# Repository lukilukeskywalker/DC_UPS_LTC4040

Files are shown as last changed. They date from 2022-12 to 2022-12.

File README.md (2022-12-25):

# DC_UPS_LTC4040
Low power Uninterrupible Power Supply based on the LTC4040
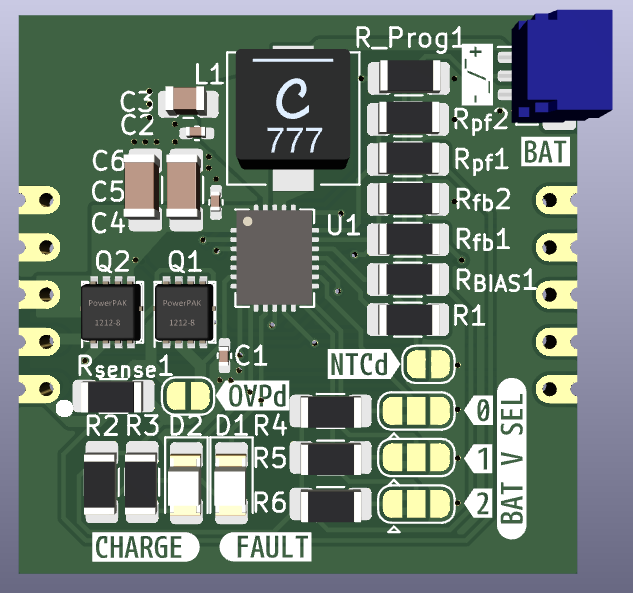
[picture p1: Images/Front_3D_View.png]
3D Board_Front


*The LTC4040 is a complete 3.5V to 5.5V supply rail battery backup system. It contains a high current step-up DC/DC regulator to back up the supply from a single-cell Li-Ion or LiFePO4 battery.*
Picked from the datasheet.

So yeah, This is supposed to be a place in module for Low Power systems that need to keep functioning when power goes off. The dimensions of the module are 30 x 30 mm, and it can be configured (as stated in the datasheet) to support different battery chemistries, and to disable or enable features like Overvoltage protection or Temperature Control of the battery

Everything is described in the schematic:
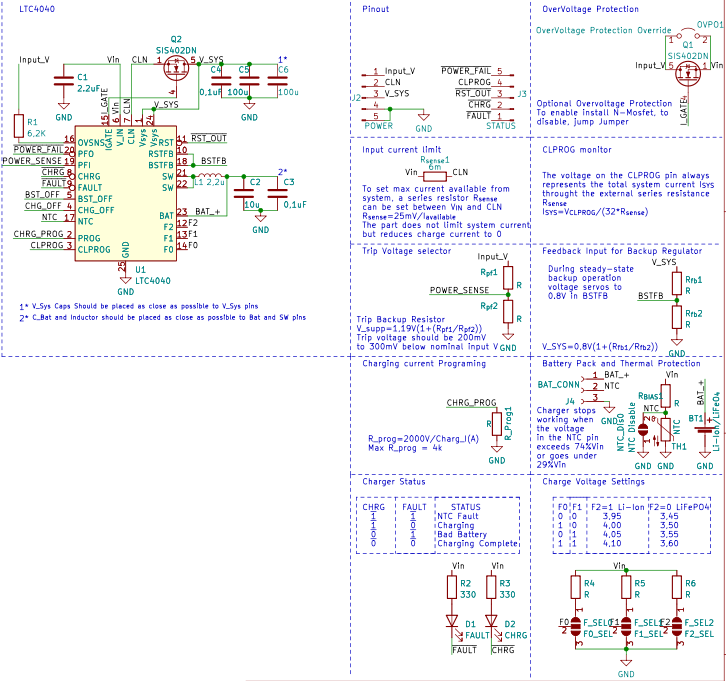
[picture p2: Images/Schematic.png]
Schematic


And the board design is Included:

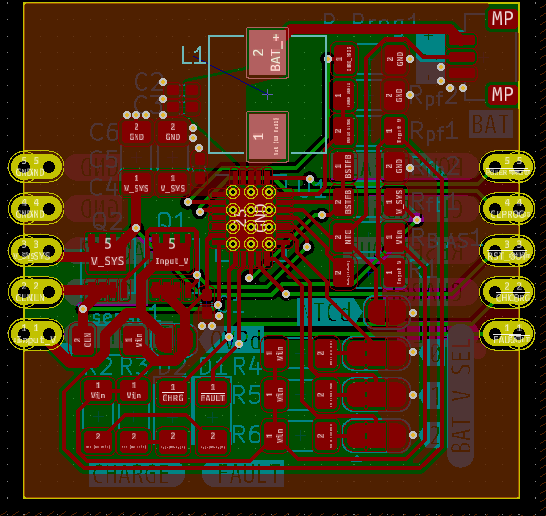
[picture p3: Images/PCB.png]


The board hasn't been tested yet, so take with care. 
Also I do not take any responsability or problems that may arrise with its use

### Proyects that may arrise Interest to the readers:
- [The Ultimate Single Cell Lithium UPS for any Raspberry Pi](https://hackaday.io/project/162653/logs?sort=oldest)
- [LTC4040 5V, 2.5A Uninterruptible Power Supply (UPS) with USB-C](https://www.beyondlogic.org/ltc4040-5v-2-5a-uninterruptible-power-supply-ups-with-usb-c/)

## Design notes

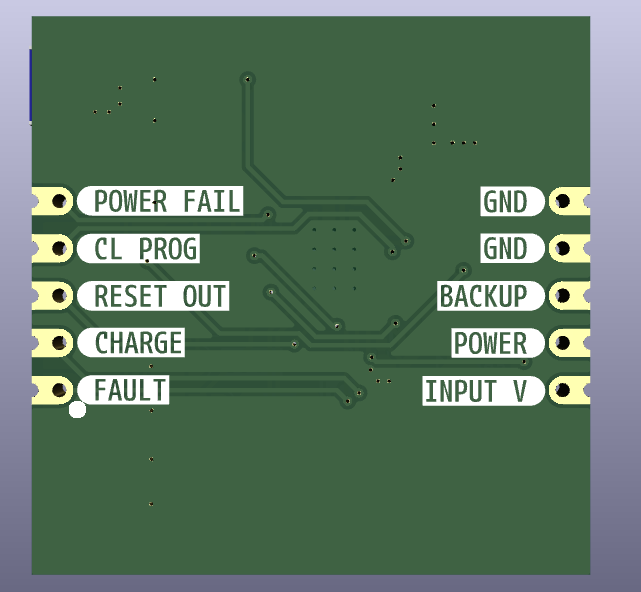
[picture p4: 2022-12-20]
Images/Back_3D_View.png

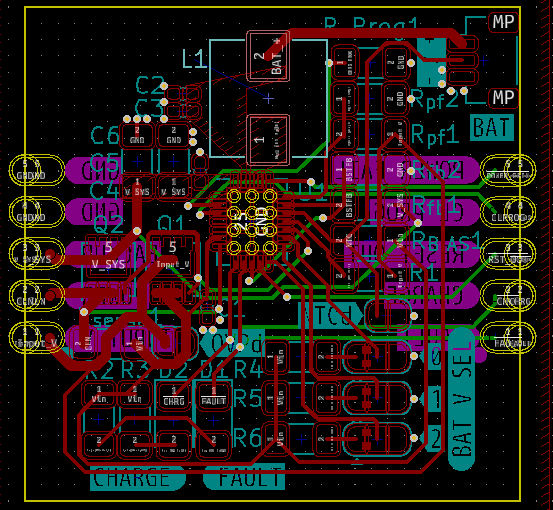
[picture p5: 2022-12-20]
Images/PCB INLINE VIEW.png

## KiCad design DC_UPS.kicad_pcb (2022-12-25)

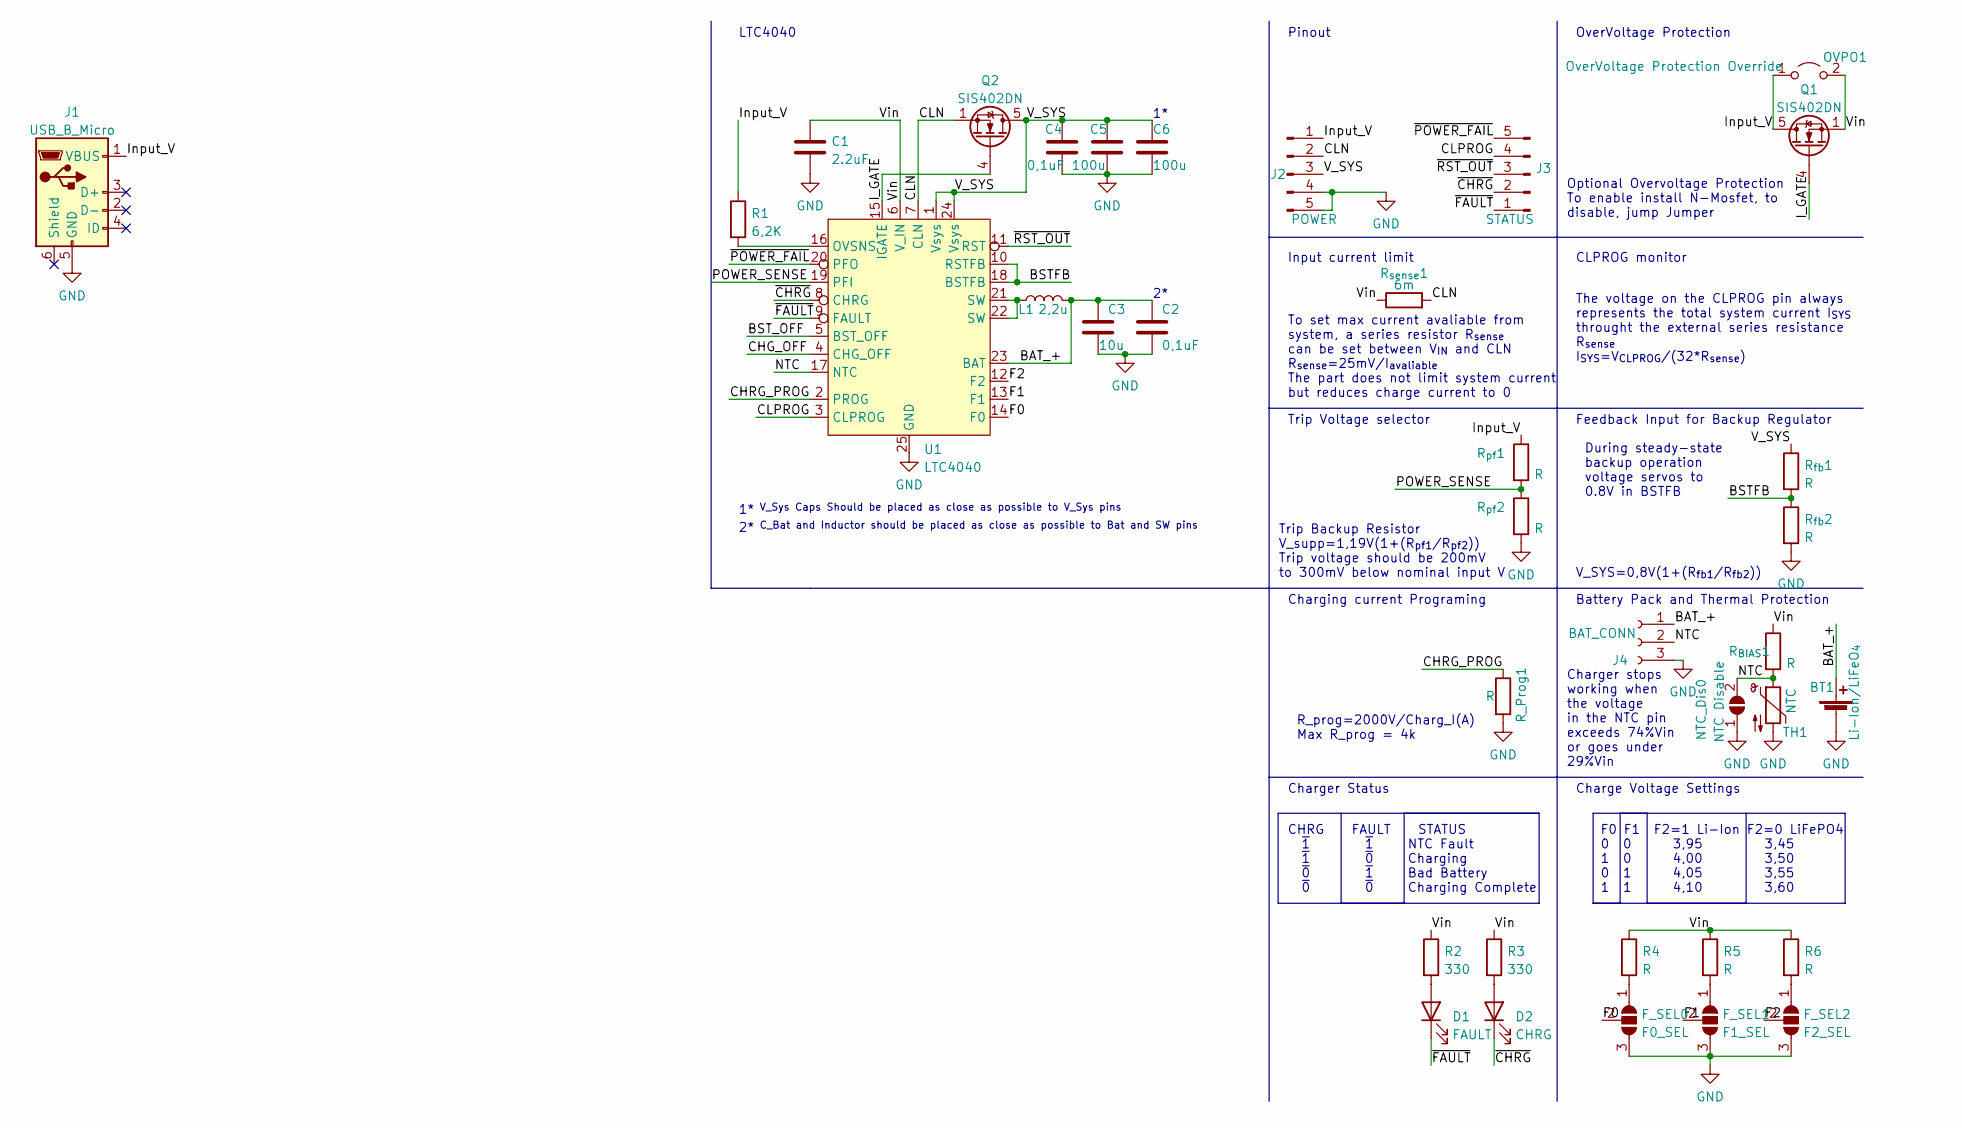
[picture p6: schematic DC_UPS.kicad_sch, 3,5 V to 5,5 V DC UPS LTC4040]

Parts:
BT1: Li-Ion/LiFeO_{4}; TE_1776119-2
C1: 2.2uF; C_0402_1005Metric_Pad0.74x0.62mm_HandSolder
C2, C4: 0,1uF; C_0402_1005Metric_Pad0.74x0.62mm_HandSolder
C3: 10u; C_0805_2012Metric_Pad1.18x1.45mm_HandSolder
C5, C6: 100u; C_1206_3216Metric_Pad1.33x1.80mm_HandSolder
D1: FAULT; LED_1206_3216Metric_Pad1.42x1.75mm_HandSolder
D2: CHRG; LED_1206_3216Metric_Pad1.42x1.75mm_HandSolder
F_SEL0: F0_SEL; SolderJumper-3_P1.3mm_Bridged2Bar12_RoundedPad1.0x1.5mm
F_SEL1: F1_SEL; SolderJumper-3_P1.3mm_Bridged2Bar12_RoundedPad1.0x1.5mm
F_SEL2: F2_SEL; SolderJumper-3_P1.3mm_Bridged2Bar12_RoundedPad1.0x1.5mm
J1: USB_B_Micro; TE_2013499-1
J2: POWER; CastellatedPinHeader_2.54mm_5
J3: STATUS; CastellatedPinHeader_2.54mm_5
J4: BAT_CONN; JST_SH_BM03B-SRSS-TB_1x03-1MP_P1.00mm_Vertical
L1: 2,2u; L_Wuerth_HCI-7030
NTC_Dis0: NTC Disable; SolderJumper-2_P1.3mm_Open_RoundedPad1.0x1.5mm
OVPO1: OverVoltage Protection Override; SolderJumper-2_P1.3mm_Open_RoundedPad1.0x1.5mm
Q1, Q2: SIS402DN; Vishay_PowerPAK_1212-8_Single
R1: 6,2K; R_1206_3216Metric_Pad1.30x1.75mm_HandSolder
R2, R3: 330; R_1206_3216Metric_Pad1.30x1.75mm_HandSolder
R4, R5, R6: R; R_1206_3216Metric_Pad1.30x1.75mm_HandSolder
R_Prog1: R; R_1206_3216Metric_Pad1.30x1.75mm_HandSolder
R_{BIAS}1: R; R_1206_3216Metric_Pad1.30x1.75mm_HandSolder
R_{fb}1, R_{fb}2: R; R_1206_3216Metric_Pad1.30x1.75mm_HandSolder
R_{pf}1, R_{pf}2: R; R_1206_3216Metric_Pad1.30x1.75mm_HandSolder
R_{sense}1: 6m; R_1206_3216Metric_Pad1.30x1.75mm_HandSolder
TH1: NTC; R_Axial_DIN0204_L3.6mm_D1.6mm_P2.54mm_Vertical
U1: LTC4040; QFN-24-1EP_4x5mm_P0.5mm_EP2.65x3.65mm_ThermalVias

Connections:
/BAT_+: BT1.1 (+), C2.1, C3.1, J4.1, L1.2, U1.23 (BAT)
/BSTFB: R_{fb}1.2, R_{fb}2.1, U1.10 (RSTFB), U1.18 (BSTFB)
/BST_OFF: U1.5 (BST_OFF)
/CHG_OFF: U1.4 (CHG_OFF)
/CHRG_PROG: R_Prog1.1, U1.2 (PROG)
/CLN: J2.2, Q2.1 (S), Q2.2 (S), Q2.3 (S), R_{sense}1.2, U1.7 (CLN)
/CLPROG: J3.4, U1.3 (CLPROG)
/F0: F_SEL0.2 (C), U1.14 (F0)
/F1: F_SEL1.2 (C), U1.13 (F1)
/F2: F_SEL2.2 (C), U1.12 (F2)
/I_GATE: Q1.4 (G), Q2.4 (G), U1.15 (IGATE)
/Input_V: J1.1 (VBUS), J2.1, OVPO1.1 (A), Q1.5 (D), R1.1, R_{pf}1.1
/NTC: J4.2, NTC_Dis0.2 (B), R_{BIAS}1.2, TH1.1, U1.17 (NTC)
/POWER_SENSE: R_{pf}1.2, R_{pf}2.1, U1.19 (PFI)
/V_SYS: C4.1, C5.1, C6.1, J2.3, Q2.5 (D), R_{fb}1.1, U1.1 (Vsys), U1.24 (Vsys)
/Vin: C1.1, OVPO1.2 (B), Q1.1 (S), Q1.2 (S), Q1.3 (S), R2.1, R3.1, R4.1, R5.1, R6.1, R_{BIAS}1.1, R_{sense}1.1, U1.6 (V_IN)
/~CHRG: D2.1 (K), J3.2, U1.8 (CHRG)
/~FAULT: D1.1 (K), J3.1, U1.9 (FAULT)
/~POWER_FAIL: J3.5, U1.20 (PFO)
/~RST_OUT: J3.3, U1.11 (RST)
GND: BT1.2 (-), C1.2, C2.2, C3.2, C4.2, C5.2, C6.2, F_SEL0.3 (B), F_SEL1.3 (B), F_SEL2.3 (B), J1.5 (GND), J2.4, J2.5, J4.3, NTC_Dis0.1 (A), R_Prog1.2, R_{fb}2.2, R_{pf}2.2, TH1.2, U1.25 (GND)
unnamed: D1.2 (A), R2.2
unnamed: D2.2 (A), R3.2
unnamed: F_SEL0.1 (A), R4.2
unnamed: F_SEL1.1 (A), R5.2
unnamed: F_SEL2.1 (A), R6.2
unnamed: L1.1, U1.21 (SW), U1.22 (SW)
unnamed: R1.2, U1.16 (OVSNS)

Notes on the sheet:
To set max current avaliable from system, a series resistor R_{sense} can be set between V_{IN} and CLN R_{sense}=25mV/I_{avaliable} The part does not limit system current but reduces charge current to 0
Charging current Programing
Charger stops working when the voltage in the NTC pin exceeds 74%Vin or goes under 29%Vin
CHRG FAULT STATUS ~{1} ~{1} NTC Fault ~{1} ~{0} Charging ~{0} ~{1} Bad Battery ~{0} ~{0} Charging Complete
During steady-state backup operation voltage servos to 0.8V in BSTFB
F0 F1 F2=1 Li-Ion F2=0 LiFePO4 0 0 3,95 3,45 1 0 4,00 3,50 0 1 4,05 3,55 1 1 4,10 3,60
1*^{ V_Sys Caps Should be placed as close as possible to V_Sys pins}
Charge Voltage Settings
Input current limit
Charger Status
V_SYS=0,8V(1+(R_{fb1}/R_{fb2}))
Trip Voltage selector
Optional Overvoltage Protection To enable install N-Mosfet, to disable, jump Jumper
LTC4040
CLPROG monitor
Trip Backup Resistor V_supp=1,19V(1+(R_{pf1}/R_{pf2})) Trip voltage should be 200mV to 300mV below nominal input V
Battery Pack and Thermal Protection
The voltage on the CLPROG pin always represents the total system current I_{SYS} throught the external series resistance R_{sense} I_{SYS}=V_{CLPROG}/(32*R_{sense})
Feedback Input for Backup Regulator
2*^{ C_Bat and Inductor should be placed as close as possible to Bat and SW pins}
Pinout
OverVoltage Protection
R_prog=2000V/Charg_I(A) Max R_prog = 4k

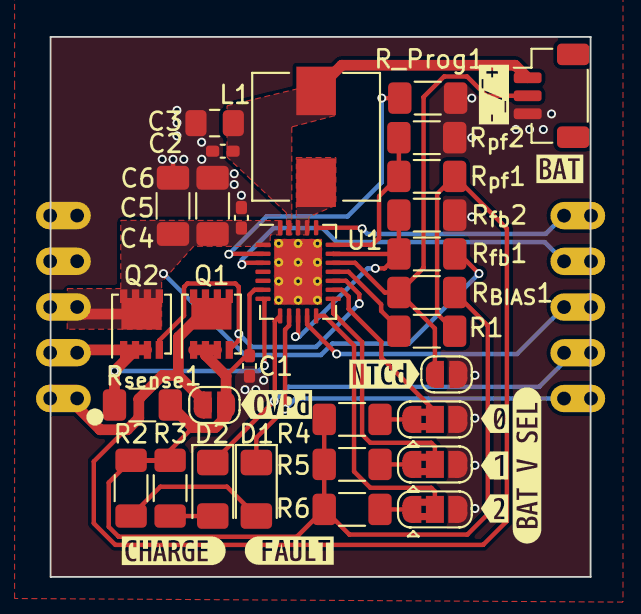
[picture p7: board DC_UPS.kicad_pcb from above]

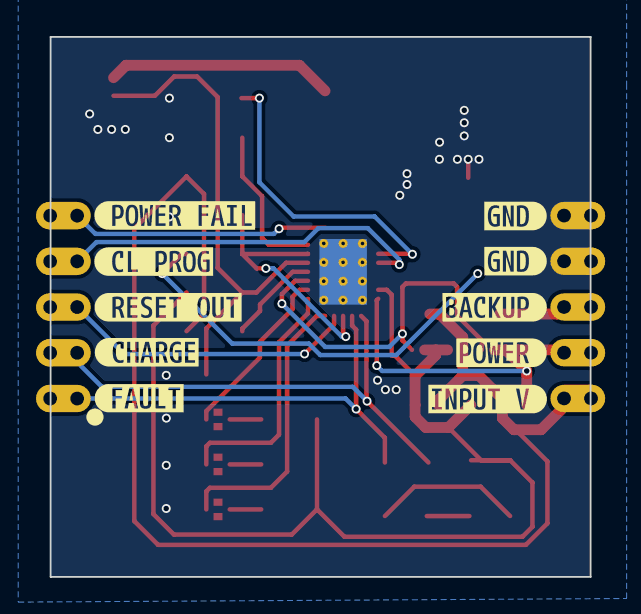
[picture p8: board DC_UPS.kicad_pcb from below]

Board: 2 copper layers, 30.0 x 30.0 mm, 53 parts (11 on the bottom side), 26 nets.

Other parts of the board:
kibuzzard-63A1A2AA: G***; kibuzzard-63A1A2AA
kibuzzard-63A1A4C9: G***; kibuzzard-63A1A4C9
kibuzzard-63A1A047: G***; kibuzzard-63A1A047
kibuzzard-63A1A50F: G***; kibuzzard-63A1A50F
kibuzzard-63A1A71E: G***; kibuzzard-63A1A71E
kibuzzard-63A1A72A: G***; kibuzzard-63A1A72A
kibuzzard-63A1A128: G***; kibuzzard-63A1A128
kibuzzard-63A1A287: G***; kibuzzard-63A1A287
kibuzzard-63A1A543: G***; kibuzzard-63A1A543
kibuzzard-63A1A568, kibuzzard-63A1A568#2: G***; kibuzzard-63A1A568
kibuzzard-63A1A734: G***; kibuzzard-63A1A734
kibuzzard-63A1A785: G***; kibuzzard-63A1A785
kibuzzard-63A1A798: G***; kibuzzard-63A1A798
kibuzzard-63A19CFD: G***; kibuzzard-63A19CFD
kibuzzard-63A19D4B: G***; kibuzzard-63A19D4B
kibuzzard-63A19D17: G***; kibuzzard-63A19D17
kibuzzard-63A19E71: G***; kibuzzard-63A19E71
kibuzzard-63A19F8A: G***; kibuzzard-63A19F8A
kibuzzard-63A19F98: G***; kibuzzard-63A19F98

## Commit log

2022-12-12 [Schematic] Initial commit
    [DC_UPS.kicad_pcb, DC_UPS.kicad_sch]
2022-12-15 [Board]Build board without connectors
    [DC_UPS.kicad_pcb, DC_UPS.kicad_sch]
2022-12-20 [Board]Finish product rev 1
    [DC_UPS.kicad_pcb, DC_UPS.kicad_sch]
